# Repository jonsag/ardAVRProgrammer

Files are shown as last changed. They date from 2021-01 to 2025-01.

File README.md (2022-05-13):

# ardATProgrammer

Some code and a shield for programming ATMega328 and ATtiny85

## Additional Boards Managers URL

Insert these URLs in File -> Preferences -> Settings tab  

>damellis: [https://raw.githubusercontent.com/damellis/attiny/ide-1.6.x-boards-manager/package_damellis_attiny_index.json](https://raw.githubusercontent.com/damellis/attiny/ide-1.6.x-boards-manager/package_damellis_attiny_index.json)  
>leonardomilliani: [http://www.leonardomiliani.com/repository/package_leonardomiliani.com_index.json](http://www.leonardomiliani.com/repository/package_leonardomiliani.com_index.json)  
>carlosefr: [https://raw.githubusercontent.com/carlosefr/atmega/master/package_carlosefr_atmega_index.json](https://raw.githubusercontent.com/carlosefr/atmega/master/package_carlosefr_atmega_index.json)  

Then install boards in Tools -> Board -> Boards manager...  

>attiny  
>ATtiny extra Boards  
>ATmega 168P/328P Boards  
>Barebones ATmega Chips (no bootloader)  

## Burn bootloader, settings

### ATtiny85

Board -> ATtiny Microcontrollers -> ATtiny 25/45/85  
Processor -> ATtiny85  
Clock -> ...  
Programmer -> Arduino as ISP  

### ATtiny2313

Board -> ATtiny MCUs -> ATtiny2313/4313  
Micro -> ATtiny2313 @ ...  
Programmer -> Arduino as ISP

### ATmega328P

Board -> Arduino AVR Boards -> Arduino Duemilanove or or Diecimila  
Processor -> ATmega 328P  
Programmer -> Arduino as AVR  

or  

Board -> Atmega168/328 -> Atmega168/328  
Micro -> ATmega328P @ ... w/Arduino as ISP  

### ATmega328

Board -> ATmega Microcontrollers -> ATmega328/328P  
Processor -> ATmega328  
Clock -> ...  
Programmer -> Arduino as ISP  

## Program AVR, settings

### ATtiny85

Board -> ATtiny Microcontrollers -> ATtiny 25/45/85  
Processor -> ATtiny85  
Clock -> ...  
Programmer -> Arduino as ISP

### ATtiny2313

Board -> ATtiny MCUs -> ATtiny2313/4313  
Micro -> ATtiny2313 @ ...  
Programmer -> Arduino as ISP

### ATmega328P

Board -> Arduino AVR Boards -> Arduino Duemilanove or or Diecimila  
Processor -> ATmega 328P  
Programmer -> Arduino as AVR  

or  

Board -> Atmega168/328 -> Atmega168/328  
Micro -> ATmega328P @ ... w/Arduino as ISP

### ATmega328

Board -> ATmega Microcontrollers -> ATmega328/328P  
Processor -> ATmega328  
Clock -> ...  
Programmer -> Arduino as ISP

## Pin Mapping, Arduino IDE -> AVR

### Arduino code -> ATtiny85 pin number -> Pin name -> Function

0 -> 5 -> PB0 -> (PWM, AIN0)  
1 -> 6 -> PB1 -> (PWM, AIN1)  
2 -> 7 -> PB2 -> (ADC1)  
3 -> 2 -> PB3 -> (ADC3)  
4 -> 3 -> PB4 -> (ADC2)  
5 -> 1 -> PB5 -> (RESET, ADC0)  

### Arduino code -> ATmega328 pin number -> Pin name -> Function

  -> 1 -> PC6 -> (RESET)  
0 -> 2 -> PD0 -> Digital pin 0 (Rx)  
1 -> 3 -> PD1 -> Digital pin 1 (Tx)  
2 -> 4 -> PD2 -> Digital pin 2  
3 -> 5 -> PD3 -> Digital pin 3 (PWM)  
4 -> 6 -> PD4 -> Digital pin 4  
5 -> 11 -> PD5 -> Digital pin 5  
6 -> 12 -> PD6 -> Digital pin 6  
7 -> 13 -> PD7 -> Digital pin 7  
8 -> 14 -> PB0 -> Digital pin 8  
9 -> 15 -> PB1 -> Digital pin 9 (PWM)  
10 -> 16 -> PB2 -> Digital pin 10 (PWM)  
11 -> 17 -> PB3 -> Digital pin 11 (PWM)  
12 -> 18 -> PB4 -> Digital pin 12  
13 -> 19 -> PB5 -> Digital pin 13  
14 -> 23 -> PC0 -> Analog input 0  
15 -> 24 -> PC1 -> Analog input 1  
16 -> 25 -> PC2 -> Analog input 2  
17 -> 26 -> PC3 -> Analog input 3  
18 -> 27 -> PC4 -> Analog input 4  
19 -> 28 -> PC5 -> Analog input 5  

## Atmega_Board_Programmer

### attiny85@16MHz internal

#### Before bootburning

>Signature = 0x1E 0x93 0x0B  
>Processor = ATtiny85  
>Flash memory size = 8192 bytes.  
>LFuse = 0x62  
>HFuse = 0xDF  
>EFuse = 0xFF  
>Lock byte = 0xFF  
>Clock calibration = 0x91  
>No bootloader support.  
>  
>First 256 bytes of program memory:  
>  
>00: 0xFF 0xFF 0xFF 0xFF 0xFF 0xFF 0xFF 0xFF ...  

#### After bootburning

>Signature = 0x1E 0x93 0x0B  
>Processor = ATtiny85  
>Flash memory size = 8192 bytes.  
>LFuse = 0xF1  
>HFuse = 0xDF  
>EFuse = 0xFF  
>Lock byte = 0xFF  
>Clock calibration = 0x86  
>No bootloader support.  
>  
>First 256 bytes of program memory:  
>  
>00: 0xFF 0xFF 0xFF 0xFF 0xFF 0xFF 0xFF 0xFF ...  

#### After programming

>Signature = 0x1E 0x93 0x0B  
>Processor = ATtiny85  
>Flash memory size = 8192 bytes.  
>LFuse = 0xF1  
>HFuse = 0xDF  
>EFuse = 0xFF  
>Lock byte = 0xFF  
>Clock calibration = 0x86  
>No bootloader support.  
>  
>First 256 bytes of program memory:  
>  
>00: 0x23 0xC0 0x32 0xC0 0x31 0xC0 0x30 0xC0 ...  

### ATmega328P as 'Arduino Duemilanove or Diecimila'

#### After bootburning

>Signature = 0x1E 0x95 0x0F  
>Processor = ATmega328P  
>Flash memory size = 32768 bytes.  
>LFuse = 0xFF  
>HFuse = 0xDA  
>EFuse = 0xFD  
>Lock byte = 0xCF  
>Clock calibration = 0xA5  
>Bootloader in use: Yes  
>EEPROM preserved through erase: No  
>Watchdog timer always on: No  
>Bootloader is 2048 bytes starting at 7800  
>  
>Bootloader:  
>  
>7800: 0x0C 0x94 0x34 0x3C 0x0C 0x94 0x51 0x3C ...  
>...  
>MD5 sum of bootloader = 0x0A 0xAC 0xF7 0x16 0xF4 0x3C 0xA2 0xC9 0x27 0x7E 0x08 0xB9 0xD6 0x90 0xBC 0x02  
>Bootloader name: ATmegaBOOT_168_atmega328  
>  
>First 256 bytes of program memory:  
>  
>00: 0xFF 0xFF 0xFF 0xFF 0xFF 0xFF 0xFF 0xFF ...  

### ATmega328 as 'ATmega328/328P' @1Mhz Internal

#### After bootburning

>Signature = 0x1E 0x95 0x14  
>Processor = ATmega328  
>Flash memory size = 32768 bytes.  
>LFuse = 0x62  
>HFuse = 0xDB  
>EFuse = 0xFD  
>Lock byte = 0xFF  
>Clock calibration = 0xA9  
>Bootloader in use: No  
>EEPROM preserved through erase: No  
>Watchdog timer always on: No  
>Bootloader is 1024 bytes starting at 7C00  
>  
>Bootloader:  
>  
>7C00: 0xFF 0xFF 0xFF 0xFF 0xFF 0xFF 0xFF 0xFF ...  
>...  
>MD5 sum of bootloader = 0x69 0x42 0x94 0x9C 0x5B 0x44 0x30 0xAE 0xF6 0x63 0x8B 0x89 0xBF 0xE1 0x73 0x2B  
>Bootloader MD5 sum not known.  
>  
>First 256 bytes of program memory:  
>  
>00: 0xFF 0xFF 0xFF 0xFF 0xFF 0xFF 0xFF 0xFF ...  

#### After programming

>Signature = 0x1E 0x95 0x14  
>Processor = ATmega328  
>Flash memory size = 32768 bytes.  
>LFuse = 0x62  
>HFuse = 0x01  
>EFuse = 0xFD  
>Lock byte = 0xFF  
>Clock calibration = 0xA9  
>Bootloader in use: No  
>EEPROM preserved through erase: No  
>Watchdog timer always on: No  
>Bootloader is 2048 bytes starting at 7800  
>  
>Bootloader:  
>  
>7800: 0xFF 0xFF 0xFF 0xFF 0xFF 0xFF 0xFF ...  
>  
>MD5 sum of bootloader = 0xCB 0xAC 0x33 0x2A 0x4E 0x08 0xAC 0xA7 0xCF 0xFF 0xE0 0xB1 0x42 0xAA 0x0C 0x65  
>Bootloader MD5 sum not known.  
>  
>First 256 bytes of program memory:  
>  
>00: 0x0C 0x94 0x5C 0x00 0x0C 0xCD 0x6E 0x00 ...  
### ATmega328 as 'ATmega328/328P' @8Mhz Internal

#### After bootburning  

>Signature = 0x1E 0x95 0x14  
>Processor = ATmega328  
>Flash memory size = 32768 bytes.  
>LFuse = 0xE2  
>HFuse = 0xDB  
>EFuse = 0xFD  
>Lock byte = 0xFF  
>Clock calibration = 0xA8  
>Bootloader in use: No  
>EEPROM preserved through erase: No  
>Watchdog timer always on: No  
>Bootloader is 2048 bytes starting at 7800  
>  
>Bootloader:  
>  
>7800: 0xFF 0xFF 0xFF 0xFF 0xFF 0xFF 0xFF 0xFF ...  
>...  
>MD5 sum of bootloader = 0xE0 0xDE 0xEB 0xD3 0xC3 0xF5 0x60 0x21 0x2A 0xF1 0x7C 0x68 0xB9 0x34 0x4B 0xAE  
>No bootloader (all 0xFF)  
>  
>First 256 bytes of program memory:  
>  
>00: 0xFF 0xFF 0xFF 0xFF 0xFF 0xFF 0xFF 0xFF ...  

#### After programming

>Signature = 0x1E 0x95 0x14  
>Processor = ATmega328  
>Flash memory size = 32768 bytes.  
>LFuse = 0xE2  
>HFuse = 0xDB  
>EFuse = 0xFD  
>Lock byte = 0xFF  
>Clock calibration = 0xA8  
>Bootloader in use: No  
>EEPROM preserved through erase: No  
>Watchdog timer always on: No  
>Bootloader is 2048 bytes starting at 7800  
>  
>Bootloader:  
>  
>7800: 0xFF 0xFF 0xFF 0xFF 0xFF 0xFF 0xFF ...  
>...  
>MD5 sum of bootloader = 0xE0 0xDE 0xEB 0xD3 0xC3 0xF5 0x60 0x21 0x2A 0xF1 0x7C 0x68 0xB9 0x34 0x4B 0xAE  
>No bootloader (all 0xFF)  
>  
>First 256 bytes of program memory:  
>  
>00: 0x0C 0x94 0x5C 0x00 0x0C 0x94 0x6E 0x00 ...  

## Resources

[Breadboard @gammon.com](http://www.gammon.com.au/breadboard) (excellent!)  
[nickgammon arduino sketches @github](https://github.com/nickgammon/arduino_sketches)  
[Alternative Atmega bootloader programmer @gammon.com](http://www.gammon.com.au/forum/?id=11635)  
[Phenoptix @github](https://github.com/phenoptix/AVRISP)

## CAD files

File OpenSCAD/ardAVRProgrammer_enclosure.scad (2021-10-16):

// ardAVRProgrammer_enclosure.scad

// Design: Jon Sagebrand
// jonsagebrand@gmail.com

// pin headers by Niccolo Rigacci <niccolo@rigacci.org>

// arduino module by ?
include <../../myCAD/OpenSCADlibraries/Arduino.scad>

// LED module by ?
include <../../myCAD/OpenSCADlibraries/led.scad>

// NOP scad library by nophead, https://github.com/nophead/NopSCADlib
include <../../myCAD/OpenSCADlibraries/NopSCADlib/vitamins/dip.scad>

// lay out for printing
print = false;

showBottom = true;
showLid = true;

// show arduino board and shield
showArd = true;
showShield = true;

// shield type
// 0: no shield
// 1: ardAVRProgrammer
shieldType = 0;

// make the hole for the arduino power input
powHole = false;

// arduino stand offs
soBotHeight = 4;
soBotDia = 8;

soTopHeight = 1;
soTopDia = 5;

ardMountHoleDia = 2.5;

ardPosts = [[14, 2.5, soBotHeight / 2], 
            [66.1, 7.6, soBotHeight / 2], 
            [66.1, 35.5, soBotHeight / 2], 
            [15.3, 50.7, soBotHeight / 2]];

// arduino uno dimensions
ardWidth = 68.6;
ardDepth = 53.3;
ardHeight = 10.9 + 1.6;

// casing
casWallThick = 1.5;

extraWidthL = shieldType == 0 ? 2 : (shieldType == 1 ? 1 : 5 );
extraWidthR = shieldType == 0 ? 2 : (shieldType == 1 ? 18.5 : 5 );
extraDepthD = shieldType == 0 ? 6 : (shieldType == 1 ? 6.5 : 5 );
extraDepthU = shieldType == 0 ? 6 : (shieldType == 1 ? 12 : 5 );

extraHeight = shieldType == 0 ? 2 : (shieldType == 1 ? 5 : 5 );

// casing lid
lidInset = 2;
lidOffset = 0;

lidScrewHoleDia = 2.5;
lidScrewPostDia = 7;
lidScrewHoleDepth = 7;

lidThick = 1.5;

lidHoleDia = 3.5;

lidRidgeWidth = 2;

tolerance = 0.2;

///// no editing below this line
roundness = 100;

// calculations of casing outer boundaries                                     
casXL = -casWallThick - extraWidthL;
casXR = ardWidth + extraWidthL + extraWidthR + casWallThick * 2 + casXL;
casYD = -casWallThick - extraDepthD;
casYU = ardDepth + extraDepthD + extraDepthU + casWallThick * 2 + casYD;

// lid screw posts                                                             
postsY = soBotHeight + soTopHeight + ardHeight + extraHeight - lidScrewHoleDepth / 2 - lidInset;

lidPostsPos = [[casXL + lidScrewPostDia / 2 + lidOffset, 
                casYD + lidScrewPostDia / 2 + lidOffset, 
                postsY],
	       [casXR - lidScrewPostDia / 2 - lidOffset, 
                casYD + lidScrewPostDia / 2 + lidOffset, 
                postsY],
	       [casXR - lidScrewPostDia / 2 - lidOffset, 
                casYU - lidScrewPostDia / 2 - lidOffset, 
                postsY],
	       [casXL + lidScrewPostDia / 2 + lidOffset, 
                casYU - lidScrewPostDia / 2 - lidOffset, 
                postsY]];

dropPos = [[casXL + casWallThick, 
            casYD + casWallThick, 
            postsY - lidScrewHoleDepth * 1.5],
	   [casXR - casWallThick, 
            casYD + casWallThick, 
            postsY - lidScrewHoleDepth * 1.5],
	   [casXR - casWallThick, 
            casYU - casWallThick, 
            postsY - lidScrewHoleDepth * 1.5],
	   [casXL + casWallThick, 
            casYU - casWallThick, 
            postsY - lidScrewHoleDepth * 1.5]];

////////// the drawing //////////

if ((showArd) && (!print)) {
  translate([0, 53.3, soBotHeight + soTopHeight])
    rotate([0, 0, -90])
    arduinoUno();
 }

if ((showShield) && (!print) && (shieldType)) {
  if (shieldType == 1) {
    translate([0.45, 0.35, 17.9])
      shieldType1();
  }
}

union() {
  if (showBottom) {
    ardMountPosts();
    bottomCasing();
  }
}

//ardMountPosts();
if (showLid) {
  if (print) {
    rotate([180, 0, 0])
      translate([0, 30, 0])
      difference() {
        lid();
        if (shieldType == 1) {
          lidOpeningsType1();
        }
      }
  } else {
    translate([0, 0, soBotHeight + soTopHeight + ardHeight + extraHeight])
    difference() {
      lid();
      if (shieldType == 1) {
        lidOpeningsType1();
      }
    }
  }
 }

module ardMountPosts() {
  for (i = [0 : 1 : 3]) { 
    
    translate(ardPosts[i])
      difference() {
      union() {
	color("blue")
	  cylinder(h = soBotHeight, r1 = soBotDia / 2, r2 = soTopDia / 2, 
		   center = true, $fn = roundness);
	
	color("green")
	  translate([0, 0, soBotHeight / 2 + soTopHeight / 2])
	  cylinder(h = soTopHeight, r1 = soTopDia / 2, r2 = soTopDia / 2, 
		   center = true, $fn = roundness);
	
      }
      
      color("red")
	translate([0, 0, soBotHeight / 2])
        cylinder(h = soBotHeight + soTopHeight, 
		 r1 = ardMountHoleDia / 2, r2 = ardMountHoleDia / 2, 
		 center = true, $fn = roundness);
      
    }
  }
}

module bottomCasing() {
  
  union() {
    translate([-extraWidthL - casWallThick, -extraDepthD - casWallThick, -casWallThick])
      difference() { // bottom part
      color("lightgrey")
	cube([ardWidth + extraWidthL + extraWidthR + casWallThick * 2, 
	      ardDepth + extraDepthD + extraDepthU + casWallThick * 2, 
	      soBotHeight + soTopHeight + ardHeight + casWallThick + extraHeight]);
      
      translate([casWallThick, casWallThick, casWallThick + 0.01])
	color("red")
	cube([ardWidth + extraWidthL + extraWidthR, 
	      ardDepth + extraDepthD + extraDepthU, 
	      soBotHeight + soTopHeight + ardHeight + extraHeight]);
      
      // usb port
      translate([0, 30.2 + casWallThick + extraDepthD, 
		 casWallThick + soBotHeight + soTopHeight])
	color("red")
	cube([casWallThick, 12 + 2, 10.9 + 2]);
      
      // power supply
      if (powHole) {
	translate([0, 3.3 + casWallThick + extraDepthD, 
		   casWallThick + soBotHeight + soTopHeight + 2])
	  union() {
	  //color("red")
	  //cube([casWallThick, 8.9 + 2, 8.9 / 2 + 1]);
	  
	  translate([0, 8.9 / 2 + 1, 8.9 / 2 + 1])
	    rotate([0, 90, 0])
	    cylinder(h = casWallThick, r1 = 8.9 / 2 + 1, r2 = 8.9 / 2 + 1, $fn = roundness);
	}
      }
    }
    
    // lid screw posts
    translate([0, 0, 0])
      for (j = [0 : 1 : 3]) {
	difference() {
	  hull() {
	    translate(lidPostsPos[j])
	      cylinder(h = lidScrewHoleDepth, 
		       r1 = lidScrewPostDia / 2, r2 = lidScrewPostDia / 2, 
		       center = true, $fn = roundness);
	    
	    translate(dropPos[j])
	      cylinder(h = 0.1, r1 = 0.1, r2 = 0.1, center = true, $fn = roundness);
	    
	  }
	  
	  // screw Holes
	  translate(lidPostsPos[j])
	    color("red")
	    cylinder(h = lidScrewHoleDepth, 
		     r1 = lidScrewHoleDia / 2, r2 = lidScrewHoleDia / 2, 
		     center = true, $fn = roundness);
	}
      }    
  }
}

//------------------------------------------------------------------------
// OpenSCAD models of miscellaneous components and devices:
// Pin headers, SD-Card, Edimax WiFi nano dongle, etc.
//
// Author:      Niccolo Rigacci <niccolo@rigacci.org>
// Version:     1.0 2017-12-14
// License:     GNU General Public License v3.0
//------------------------------------------------------------------------

//------------------------------------------------------------------------
// Matrix of 2.54 mm pins.
//------------------------------------------------------------------------
module pin_headers(cols, rows) {
  w = 2.54; h = 2.54; p = 0.65;
  for(x = [0 : (cols -1)]) {
    for(y = [0 : (rows  - 1)]) {
      translate([w * x, w * y, 0]) {
	union() {
	  color("black") 
	    cube([w, w, h]);
	  color("gold")  
	    translate([(w - p) / 2, (w - p) / 2, -3]) cube([p, p, 11.54]);
	}
      }
    }
  }
}

module shieldType1() {
  translate([0, 0, 0]) // PCB
    color("green")
    cube([86.36, 58.42, 1.6]);
  
  // pin headers connecting to Arduino
  translate([28.57 - 2.54, 3.17 - 2.54, 0])
    rotate([180, 0, 90])
    pin_headers(1, 8);
  
  translate([51.44 - 2.54, 3.17 - 2.54, 0])
    rotate([180, 0, 90])
    pin_headers(1, 6);
  
  translate([19.68 - 2.54, 51.44 - 2.54, 0])
    rotate([180, 0, 90])
    pin_headers(1, 10);
  
  translate([46.35 - 2.54, 51.44 - 2.54, 0])
    rotate([180, 0, 90])
    pin_headers(1, 8);
  
  // LEDs
  //translate([79.38, 54.61, 1.6 + 1.5])
  translate([80.64, 54.61, 1.6 + 1.5])
    led(5, "blue", legs = false);

  translate([80.64, 46.35, 1.6 + 1.5])
    led(5, "red", legs = false);
  
  translate([80.64, 38.10, 1.6 + 1.5])
    led(5, "green", legs = false);
  
  // headers
  translate([59.69 - 2.54 / 2, 13.34 - 2.54 / 2, 2.54 / 2 + 0.4])
    rotate([0, 0, 0])
    pin_headers(2, 3);
  
  translate([59.69 - 2.54 / 2, 28.57 - 2.54 / 2, 2.54 / 2 + 0.4])
    rotate([0, 0, 0])
    pin_headers(2, 5);
  
  
  //  28 pin ZIF
  translate([11.43, 12.06, 1.7])
    zif28();
  /*
    translate([11.43 + 2.54 * 6.5, 12.7 + 2.54 * 2, 1.7])
    rotate([0, 0, 90])
    pdip(28, 2.54, socketed = true, w = inch(0.4));
  */
  // 20 pin ZIF
  translate([21.59, 35.56, 1.7])
    zif20();
  /*
    translate([21.59 + 2.54 * 4.5, 36.2 + 2.54 * 1.5, 1.7])
    rotate([0, 0, 90])
    pdip(20, 2.54, socketed = true, w = inch(0.3));
  */
  // 8 pin DIL
  translate([74.3 + 2.54 * 1.5, 5.08 + 2.54 * 1.5, 1.7])
    rotate([0, 0, 0])
    pdip(8, 2.54, socketed = true, w = inch(0.3));
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

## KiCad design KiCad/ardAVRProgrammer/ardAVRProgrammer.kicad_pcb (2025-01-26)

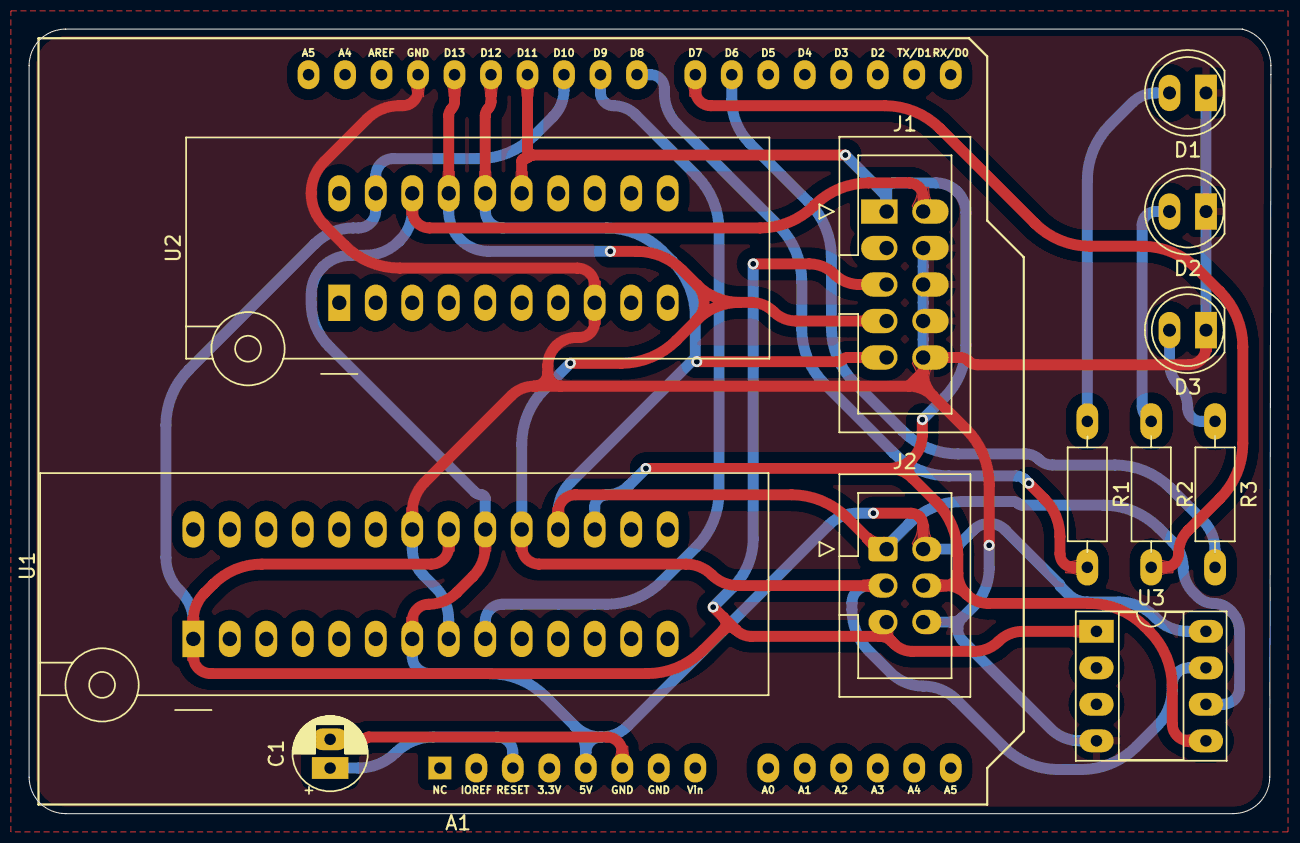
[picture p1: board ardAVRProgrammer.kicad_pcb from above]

Board: 2 copper layers, 86.4 x 54.6 mm, 13 parts (0 on the bottom side), 15 nets.

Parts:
A1: Arduino_UNO_R3; Arduino_UNO_R3_shield_large
C1: 10u; CP_Radial_D5.0mm_P2.00mm_larger
D1, D2, D3: LED; LED_D5.0mm_larger_pads
J1: 2x5_ISP_header; IDC-Header_2x05_P2.54mm_Vertical_large
J2: 2x3_ISP_header; IDC-Header_2x03_P2.54mm_Vertical large
R1, R2, R3: 330R; R_Axial_DIN0207_L6.3mm_D2.5mm_P10.16mm_Horizontal_larger_pa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
U1: ATmega328P-PU; ZIF_DIP_Socket-28_W6.9_W7.62_W7.62_W12.7_W13.5_large
U2: ATtiny2313-20M; ZIF_DIP_Socket-20_W4.3_W5.08_W7.62_W10.16_W10.9_3M_220-3342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
U3: ATtiny85-20P; DIP-8_W7.62mm_Socket_w_dip_packet_LongPads

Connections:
+5V: A1.5 (+5V), J1.2 (VCC), J2.2 (VCC), U1.7 (VCC), U1.20 (AVCC), U2.18 (VCC), U3.8 (VCC)
GND: A1.29 (GND), D1.1 (K), D2.1 (K), D3.1 (K), J1.4 (GND), J1.6 (GND), J1.8 (GND), J1.10 (GND), J2.6 (GND), U1.8 (GND), U1.22 (GND), U2.8 (GND), U3.4 (GND)
unnamed: A1.3 (~RESET), C1.1
unnamed: A1.6 (GND), C1.2
unnamed: A1.21 (D6), R3.2
unnamed: A1.22 (D7), R2.2
unnamed: A1.23 (D8), R1.2
unnamed: A1.24 (D9), U1.9 (XTAL1/PB6)
unnamed: A1.25 (D10), J1.5 (RST), J2.5 (RST), U1.1 (~RESET/PC6), U1.21 (AREF), U2.19 (PA2/~RESET), U3.1 (~RESET/PB5)
unnamed: A1.26 (D11), J1.1 (MOSI), J2.4 (MOSI), U1.17 (PB3), U2.15 (PB5), U3.5 (AREF/PB0)
unnamed: A1.27 (D12), J1.9 (MISO), J2.1 (MISO), U1.18 (PB4), U2.16 (PB6), U3.6 (PB1)
unnamed: A1.28 (D13), J1.7 (SCK), J2.3 (SCK), U1.19 (PB5), U2.17 (PB7), U3.7 (PB2)
unnamed: D1.2 (A), R1.1
unnamed: D2.2 (A), R2.1
unnamed: D3.2 (A), R3.1

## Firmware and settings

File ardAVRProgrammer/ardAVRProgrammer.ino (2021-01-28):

/* ardAVRProgrammer
 *  
 * by phenoptix
 * code from https://www.instructables.com/Building-an-ISP-Shield-for-Arduino/ 
 * 
 * /

/* Making a barebones arduino
 *  
 *  instructions from https://www.instructables.com/Programming-Chips-With-Your-Arduino-AVR-ISP-Coveri/
 *  
 *  Go to > Tools on your IDE, 
 *  Now > Programmer > Arduino as ISP. 
 *  With that checked we can then go back to > Tools > Burn Bootloader. 
 *  Now we're going to see some flashing LEDs and wait a while. 
 *  The message at the bottom of your IDE should eventually turn to Bootloading complete. 
 *  Hey presto, that chip on the breadboard can now be turned into a barebones Arduino!
 *  such as on http://start.shrimping.it/kit/shrimp.html
 *  
 */

 
// this sketch turns the Arduino into a AVRISP
// using the following pins:
// 10: slave reset
// 11: MOSI
// 12: MISO
// 13: SCK

// Put an LED (with resistor) on the following pins:
//  7: Error - Lights up if something goes wrong (use red if that makes sense)
//  8: Programming - In communication with the slave
//  6: Heartbeat - shows the programmer is running (removed, see notes below)
// Optional - Piezo speaker on pin A3
//
// October 2009 by David A. Mellis
// - Added support for the read signature command
//
// February 2009 by Randall Bohn
// - Added support for writing to EEPROM (what took so long?)
// Windows users should consider WinAVR's avrdude instead of the
// avrdude included with Arduino software.
//
// January 2008 by Randall Bohn
// - Thanks to Amplificar for helping me with the STK500 protocol
// - The AVRISP/STK500 (mk I) protocol is used in the arduino bootloader
// - The SPI functions herein were developed for the AVR910_ARD programmer
// - More information at http://code.google.com/p/mega-isp
//
// March 2012 - William Phelps
// modify to work with Arduino IDE 1.0 which has a shorter serial port receive buffer
// getEOP() now gets entire request before avrisp() is called to process it
// Serial.print((char) xxx) changed to Serial.write(xxx)
// uint8_t changed to byte
// added support for Piezo speaker
// moved Pmode LED to A0
// removed "heartbeat" on pin 6, added short blip of ERROR LED instead
// Why is it that PROG_FLASH and PROG_DATA don't actually do anything???
// Tested with Arduino IDE 22 and 1.0
// IDE 22 - 5148 bytes
// IDE 1.0 - 5524 bytes!

// January 2014 - Ben Gray
// Put the heartbeat LED back and switched around the pins a little for the LEDs.


// SLOW SPEED CHIP ERASE AND FUSE BURNING
//
// Enable LOW_SPEED to allow you to erase chips that would fail otherwise,
// for being running with a clock too slow for the programmer.
//
// This allowed me to recover several ATMega328 that had no boot loader and the
// first instruction was to set the clock to the slowest speed. Usually this
// kind of recovery requires high voltage programming, but this trick will do
// just fine.
//
// How to proceed:
// 1. Enable LOW_SPEED, and load it to the programmer.
// 2. Erase and burn the fuses on the target uC. Example for ATMega328:
//   arduino-1.0.1/hardware/tools/avrdude -Carduino-1.0.1/hardware/tools/avrdude.conf -patmega328p -cstk500v1 -P /dev/serial/by-id/usb-FTDI_FT232R_USB_UART_A900cf1Q-if00-port0 -b19200 -e -Ulock:w:0x3F:m -Uefuse:w:0x05:m -Uhfuse:w:0xDA:m -Ulfuse:w:0xF7:m
// 3. Comment LOW_SPEED and load it back to the programmer.
// 4. Program the target uC as usual. Example:
//  arduino-1.0.1/hardware/tools/avrdude -Carduino-1.0.1/hardware/tools/avrdude.conf -patmega328p -cstk500v1 -P /dev/serial/by-id/usb-FTDI_FT232R_USB_UART_A900cf1Q-if00-port0 -b19200 -Uflash:w:firmware.hex:i
//
// Note 1: EXTRA_SPI_DELAY was added to let you slow down SPI even more. You can
// play with the value if it does not work with the default.
// Note 2: LOW_SPEED will alow you only to erase the chip and burn the fuses! It
// will fail if you try to program the target uC this way!

//#define LOW_SPEED
#ifdef LOW_SPEED
#define EXTRA_SPI_DELAY 125
#else
#define EXTRA_SPI_DELAY 0
#endif

#include "pins_arduino.h"  // defines SS,MOSI,MISO,SCK
#define RESET SS

#define LED_ERR 7
#define LED_PMODE 8
#define LED_HB 6
//#define PIEZO A3

#define HWVER 2
#define SWMAJ 1
#define SWMIN 18

// STK Definitions
const byte STK_OK = 0x10;
const byte STK_FAILED = 0x11;
const byte STK_UNKNOWN = 0x12;
const byte STK_INSYNC = 0x14;
const byte STK_NOSYNC = 0x15;
const byte CRC_EOP = 0x20; //ok it is a space...

const byte STK_GET_SYNC     = 0x30;
const byte STK_GET_SIGNON   = 0x31;
const byte STK_GET_PARM     = 0x41;
const byte STK_SET_PARM     = 0x42;
const byte STK_SET_PARM_EXT = 0x45;
const byte STK_PMODE_START  = 0x50;
const byte STK_PMODE_END    = 0x51;
const byte STK_SET_ADDR     = 0x55;
const byte STK_UNIVERSAL    = 0x56;
const byte STK_PROG_FLASH   = 0x60;
const byte STK_PROG_DATA    = 0x61;
const byte STK_PROG_PAGE    = 0x64;
const byte STK_READ_PAGE    = 0x74;
const byte STK_READ_SIGN    = 0x75;

//// TONES  ==========================================
//// Start by defining the relationship between
////       note, period, &  frequency.
//#define  c     3830    // 261 Hz
//#define  d     3400    // 294 Hz
//#define  e     3038    // 329 Hz
//#define  f     2864    // 349 Hz
//#define  g     2550    // 392 Hz
//#define  a     2272    // 440 Hz
//#define  b     2028    // 493 Hz
//#define  C     1912    // 523 Hz

//void pulse(int pin, int times);

int error = 0;
int pmode = 0;
// address for reading and writing, set by STK_SET_ADDR command
int _addr;
byte _buffer[256]; // serial port buffer
int pBuffer = 0;  // buffer pointer
int iBuffer = 0;  // buffer index
byte buff[256];  // temporary buffer
boolean EOP_SEEN = false;

void setup() {

  Serial.begin(19200);
  //  pinMode(PIEZO, OUTPUT);
  //  beep(1700, 40);
  EOP_SEEN = false;
  iBuffer = pBuffer = 0;

  pinMode(LED_PMODE, OUTPUT);
  pulse(LED_PMODE, 2);
  pinMode(LED_ERR, OUTPUT);
  pulse(LED_ERR, 2);
  pinMode(LED_HB, OUTPUT);
  pulse(LED_HB, 2);

  pinMode(9, OUTPUT);
  // setup high freq PWM on pin 9 (timer 1)
  // 50% duty cycle -> 8 MHz
  OCR1A = 0;
  ICR1 = 1;
  // OC1A output, fast PWM
  TCCR1A = _BV(WGM11) | _BV(COM1A1);
  TCCR1B = _BV(WGM13) | _BV(WGM12) | _BV(CS10); // no clock prescale


}

#define beget16(addr) (*addr * 256 + *(addr+1) )
typedef struct param {
  byte devicecode;
  byte revision;
  byte progtype;
  byte parmode;
  byte polling;
  byte selftimed;
  byte lockbytes;
  byte fusebytes;
  int flashpoll;
  int eeprompoll;
  int pagesize;
  int eepromsize;
  int flashsize;
}
parameter;

parameter param;

// this provides a heartbeat on pin 6, so you can tell the software is running.
byte hbval = 128;
int8_t hbdelta = 4;
void heartbeat() {
  if (hbval > 192) hbdelta = -hbdelta;
  if (hbval < 32) hbdelta = -hbdelta;
  if (hbval > 250) hbdelta = -hbdelta;
  if (hbval < 10) hbdelta = -hbdelta;
  hbval += hbdelta;
  analogWrite(LED_HB, hbval);
  delay(20);
}

void getEOP() {
  int minL = 0;
  byte avrch = 0;
  byte bl = 0;
  while (!EOP_SEEN) {
    while (Serial.available() > 0) {
      byte ch = Serial.read();
      _buffer[iBuffer] = ch;
      iBuffer = (++iBuffer) % 256; // increment and wrap
      if (iBuffer == 1)  avrch = ch;  // save command
      if ((avrch == STK_PROG_PAGE) && (iBuffer == 3)) {
        minL = 256 * _buffer[1] + _buffer[2] + 4;
      }
      if ((iBuffer > minL) && (ch == CRC_EOP)) {
        EOP_SEEN = true;
      }
    }
    if (!EOP_SEEN) {
      heartbeat(); // light the heartbeat LED
      //     if (bl == 100) {
      //       pulse(LED_ERR,1,10);  // blink the red LED
      //       bl = 0;
      //     }
      bl++;
      delay(10);
    }
  }
}

// serialEvent not used so sketch would be compatible with older IDE versions
//void serialEvent() {
//  int minL = 0;
//  byte avrch = 0;
//  while (Serial.available()>0)
//  {
//    byte ch = Serial.read();
//    _buffer[iBuffer] = ch;
//    iBuffer = (++iBuffer)%256;  // increment and wrap
//    if (iBuffer == 1)  avrch = ch;  // save command
//    if ((avrch == STK_PROG_PAGE) && (iBuffer==3)) {
//      minL = 256*_buffer[1] + _buffer[2] + 4;
//    }
//    if ((iBuffer>minL) && (ch == CRC_EOP)) {
//      EOP_SEEN = true;
//    }
//  }
//}

void loop(void) {
  // is pmode active?
  //  if (pmode) digitalWrite(LED_PMODE, HIGH);
  //  else digitalWrite(LED_PMODE, LOW);
  digitalWrite(LED_PMODE, LOW);
  // is there an error?
  if (error) digitalWrite(LED_ERR, HIGH);
  else digitalWrite(LED_ERR, LOW);

  getEOP();

  // have we received a complete request?  (ends with CRC_EOP)
  if (EOP_SEEN) {
    digitalWrite(LED_PMODE, HIGH);
    EOP_SEEN = false;
    avrisp();
    iBuffer = pBuffer = 0;  // restart buffer
  }

}

byte getch() {
  if (pBuffer == iBuffer) {  // spin until data available ???
    pulse(LED_ERR, 1);
    //    beep(1700, 20);
    error++;
    return -1;
  }
  byte ch = _buffer[pBuffer];  // get next char
  pBuffer = (++pBuffer) % 256; // increment and wrap
  return ch;
}

void readbytes(int n) {
  for (int x = 0; x < n; x++) {
    buff[x] = getch();
  }
}

//#define PTIME 20
void pulse(int pin, int times, int ptime) {
  do {
    digitalWrite(pin, HIGH);
    delay(ptime);
    digitalWrite(pin, LOW);
    delay(ptime);
    times--;
  }
  while (times > 0);
}
void pulse(int pin, int times) {
  pulse(pin, times, 50);
}

void spi_init() {
  byte x;
  SPCR = 0x53;
#ifdef LOW_SPEED
  SPCR = SPCR | B00000011;
#endif
  x = SPSR;
  x = SPDR;
}

void spi_wait() {
  do {
  }
  while (!(SPSR & (1 << SPIF)));
}

byte spi_send(byte b) {
  byte reply;
#ifdef LOW_SPEED
  cli();
  CLKPR = B10000000;
  CLKPR = B00000011;
  sei();
#endif
  SPDR = b;
  spi_wait();
  reply = SPDR;
#ifdef LOW_SPEED
  cli();
  CLKPR = B10000000;
  CLKPR = B00000000;
  sei();
#endif
  return reply;
}

byte spi_transaction(byte a, byte b, byte c, byte d) {
  byte n;
  spi_send(a);
  n = spi_send(b);
  //if (n != a) error = -1;
  n = spi_send(c);
  return spi_send(d);
}

void replyOK() {
  //  if (EOP_SEEN == true) {
  if (CRC_EOP == getch()) {  // EOP should be next char
    Serial.write(STK_INSYNC);
    Serial.write(STK_OK);
  }
  else {
    pulse(LED_ERR, 2);
    Serial.write(STK_NOSYNC);
    error++;
  }
}

void breply(byte b) {
  if (CRC_EOP == getch()) {  // EOP should be next char
    Serial.write(STK_INSYNC);
    Serial.write(b);
    Serial.write(STK_OK);
  }
  else {
    Serial.write(STK_NOSYNC);
    error++;
  }
}

void get_parameter(byte c) {
  switch (c) {
    case 0x80:
      breply(HWVER);
      break;
    case 0x81:
      breply(SWMAJ);
      break;
    case 0x82:
      breply(SWMIN);
      break;
    case 0x93:
      breply('S'); // serial programmer
      break;
    default:
      breply(0);
  }
}

void set_parameters() {
  // call this after reading paramter packet into buff[]
  param.devicecode = buff[0];
  param.revision = buff[1];
  param.progtype = buff[2];
  param.parmode = buff[3];
  param.polling = buff[4];
  param.selftimed = buff[5];
  param.lockbytes = buff[6];
  param.fusebytes = buff[7];
  param.flashpoll = buff[8];
  // ignore buff[9] (= buff[8])
  //getch(); // discard second value

  // WARNING: not sure about the byte order of the following
  // following are 16 bits (big endian)
  param.eeprompoll = beget16(&buff[10]);
  param.pagesize = beget16(&buff[12]);
  param.eepromsize = beget16(&buff[14]);

  // 32 bits flashsize (big endian)
  param.flashsize = buff[16] * 0x01000000
                    + buff[17] * 0x00010000
                    + buff[18] * 0x00000100
                    + buff[19];

}

void start_pmode() {
  spi_init();
  // following delays may not work on all targets...
  pinMode(RESET, OUTPUT);
  digitalWrite(RESET, HIGH);
  pinMode(SCK, OUTPUT);
  digitalWrite(SCK, LOW);
  delay(50 + EXTRA_SPI_DELAY);
  digitalWrite(RESET, LOW);
  delay(50 + EXTRA_SPI_DELAY);
  pinMode(MISO, INPUT);
  pinMode(MOSI, OUTPUT);
  spi_transaction(0xAC, 0x53, 0x00, 0x00);
  pmode = 1;
}

void end_pmode() {
  pinMode(MISO, INPUT);
  pinMode(MOSI, INPUT);
  pinMode(SCK, INPUT);
  pinMode(RESET, INPUT);
  pmode = 0;
}

void universal() {
  //  int w;
  byte ch;
  //  for (w = 0; w < 4; w++) {
  //    buff[w] = getch();
  //  }
  readbytes(4);
  ch = spi_transaction(buff[0], buff[1], buff[2], buff[3]);
  breply(ch);
}

void flash(byte hilo, int addr, byte data) {
  spi_transaction(0x40 + 8 * hilo, addr >> 8 & 0xFF, addr & 0xFF, data);
}
void commit(int addr) {
  spi_transaction(0x4C, (addr >> 8) & 0xFF, addr & 0xFF, 0);
}

//#define _current_page(x) (here & 0xFFFFE0)
int current_page(int addr) {
  if (param.pagesize == 32) return addr & 0xFFFFFFF0;
  if (param.pagesize == 64) return addr & 0xFFFFFFE0;
  if (param.pagesize == 128) return addr & 0xFFFFFFC0;
  if (param.pagesize == 256) return addr & 0xFFFFFF80;
  return addr;
}
byte write_flash(int length) {
  if (param.pagesize < 1) {
    return STK_FAILED;
  }
  //if (param.pagesize != 64) return STK_FAILED;
  int page = current_page(_addr);
  int x = 0;
  while (x < length) {
    if (page != current_page(_addr)) {
      commit(page);
      page = current_page(_addr);
    }
    flash(LOW, _addr, buff[x++]);
    flash(HIGH, _addr, buff[x++]);
    _addr++;
  }
  commit(page);
  return STK_OK;
}

byte write_eeprom(int length) {
  // here is a word address, so we use here*2
  // this writes byte-by-byte,
  // page writing may be faster (4 bytes at a time)
  for (int x = 0; x < length; x++) {
    spi_transaction(0xC0, 0x00, _addr * 2 + x, buff[x]);
    delay(45);
  }
  return STK_OK;
}

void program_page() {
  byte result = STK_FAILED;
  int length = 256 * getch() + getch();
  if (length > 256) {
    Serial.write(STK_FAILED);
    error++;
    return;
  }
  char memtype = (char)getch();
  //  for (int x = 0; x < length; x++) {
  //    buff[x] = getch();
  //  }
  readbytes(length);
  if (CRC_EOP == getch()) {
    Serial.write(STK_INSYNC);
    switch (memtype) {
      case 'E':
        result = (byte)write_eeprom(length);
        break;
      case 'F':
        result = (byte)write_flash(length);
        break;
    }
    Serial.write(result);
    if (result != STK_OK) {
      error++;
    }
  }
  else {
    Serial.write(STK_NOSYNC);
    error++;
  }
}

byte flash_read(byte hilo, int addr) {
  return spi_transaction(0x20 + hilo * 8,
                         (addr >> 8) & 0xFF,
                         addr & 0xFF,
                         0);
}

char flash_read_page(int length) {
  for (int x = 0; x < length; x += 2) {
    byte low = flash_read(LOW, _addr);
    Serial.write( low);
    byte high = flash_read(HIGH, _addr);
    Serial.write( high);
    _addr++;
  }
  return STK_OK;
}

char eeprom_read_page(int length) {
  // here again we have a word address
  for (int x = 0; x < length; x++) {
    byte ee = spi_transaction(0xA0, 0x00, _addr * 2 + x, 0xFF);
    Serial.write( ee);
  }
  return STK_OK;
}

void read_page() {
  byte result = (byte)STK_FAILED;
  int length = 256 * getch() + getch();
  char memtype = getch();
  if (CRC_EOP != getch()) {
    Serial.write(STK_NOSYNC);
    return;
  }
  Serial.write(STK_INSYNC);
  if (memtype == 'F') result = flash_read_page(length);
  if (memtype == 'E') result = eeprom_read_page(length);
  Serial.write(result);
  return;
}

void read_signature() {
  if (CRC_EOP != getch()) {
    Serial.write(STK_NOSYNC);
    error++;
    return;
  }
  Serial.write(STK_INSYNC);
  byte high = spi_transaction(0x30, 0x00, 0x00, 0x00);
  Serial.write(high);
  byte middle = spi_transaction(0x30, 0x00, 0x01, 0x00);
  Serial.write(middle);
  byte low = spi_transaction(0x30, 0x00, 0x02, 0x00);
  Serial.write(low);
  Serial.write(STK_OK);
}
//////////////////////////////////////////
//////////////////////////////////////////


////////////////////////////////////
////////////////////////////////////

int avrisp() {
  byte data, low, high;
  byte avrch = getch();
  switch (avrch) {
    case STK_GET_SYNC: // get in sync
      replyOK();
      break;
    case STK_GET_SIGNON:  // get sign on
      if (getch() == CRC_EOP) {
        Serial.write(STK_INSYNC);
        Serial.write("AVR ISP");
        Serial.write(STK_OK);
      }
      break;
    case STK_GET_PARM:  // 0x41
      get_parameter(getch());
      break;
    case STK_SET_PARM:  // 0x42
      readbytes(20);
      set_parameters();
      replyOK();
      break;
    case STK_SET_PARM_EXT: // extended parameters - ignore for now
      readbytes(5);
      replyOK();
      break;
    case STK_PMODE_START:  // 0x50
      //     beep(2272, 20);
      start_pmode();
      replyOK();
      break;
    case STK_PMODE_END:  //0x51
      //      beep(1912, 50);
      error = 0;
      end_pmode();
      replyOK();
      break;
    case STK_SET_ADDR:  // 0x55
      _addr = getch() + 256 * getch();
      replyOK();
      break;
    case STK_UNIVERSAL:  //UNIVERSAL 0x56
      universal();
      break;
    case STK_PROG_FLASH: //STK_PROG_FLASH  ???
      low = getch();
      high = getch();
      replyOK();
      break;
    case STK_PROG_DATA: //STK_PROG_DATA  ???
      data = getch();
      replyOK();
      break;
    case STK_PROG_PAGE:  //STK_PROG_PAGE
      //      beep(1912, 20);
      program_page();
      break;
    case STK_READ_PAGE: //STK_READ_PAGE
      read_page();
      break;
    case STK_READ_SIGN: //STK_READ_SIGN
      read_signature();
      break;
    // expecting a command, not CRC_EOP
    // this is how we can get back in sync
    case CRC_EOP:
      Serial.write(STK_NOSYNC);
      break;
    // anything else we will return STK_UNKNOWN
    default:
      if (CRC_EOP == getch())
        Serial.write(STK_UNKNOWN);
      else
        Serial.write(STK_NOSYNC);
  }
}

// beep without using PWM
//void beep(int tone, long duration){
//  long elapsed = 0;
//  while (elapsed < (duration * 10000)) {
//    digitalWrite(PIEZO, HIGH);
//    delayMicroseconds(tone / 2);
//    digitalWrite(PIEZO, LOW);
//    delayMicroseconds(tone / 2);
// Keep track of how long we pulsed
//    elapsed += tone;
//  }
//}

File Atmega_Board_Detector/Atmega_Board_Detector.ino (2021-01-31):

// Atmega chip fuse detector
// Author: Nick Gammon
// Date: 19nd March 2017
// Version: 1.20

// Version 1.1 added signatures for Attiny24/44/84 (5 May 2012)
// Version 1.2 added signatures for ATmega8U2/16U2/32U2 (7 May 2012)
// Version 1.3: Added signature for ATmega1284P (8 May 2012)
// Version 1.4: Output an 8 MHz clock on pin 9
// Version 1.5: Corrected flash size for Atmega1284P.
// Version 1.6: Added signatures for ATtiny2313A, ATtiny4313, ATtiny13
// Version 1.7: Added signature for Atmega8A
// Version 1.8: Allowed for running on the Leonardo, Micro, etc.
// Version 1.9: Fixed bug where wrong fuse was being checked for bootloader in some cases
// Version 1.10: Added database of known signatures
// Version 1.11: Added MD5 sum for Uno Atmega16U2 (USB) bootloader
// Version 1.12: Display message if cannot enter programming mode.
// Version 1.13: Added support for At90USB82, At90USB162
// Version 1.14: Added support for ATmega328
// Version 1.15: Added preliminary support for high-voltage programming mode for Atmega328 family
// Version 1.16: Major tidy-ups, made code more modular
// Version 1.17: Added signature for Leonardo_prod_firmware_2012_12_10 bootloader
// Version 1.18: Got rid of compiler warnings in IDE 1.6.7
// Version 1.19: Added more signatures: ATmega168V, ATmega328PB, ATmega1284
// Version 1.20: Added MD5 sum for Pro Mini Optiboot bootloader (19 March 2017 by Patrick Bouffel)

const char Version [] = "1.20";

// make true to use the high-voltage parallel wiring
#define HIGH_VOLTAGE_PARALLEL false
// make true to use the high-voltage serial wiring
#define HIGH_VOLTAGE_SERIAL false
// make true to use ICSP programming
#define ICSP_PROGRAMMING true

#if HIGH_VOLTAGE_PARALLEL && HIGH_VOLTAGE_SERIAL
  #error Cannot use both high-voltage parallel and serial at the same time
#endif 

#if (HIGH_VOLTAGE_PARALLEL || HIGH_VOLTAGE_SERIAL) && ICSP_PROGRAMMING
  #error Cannot use ICSP and high-voltage programming at the same time
#endif

#if !(HIGH_VOLTAGE_PARALLEL || HIGH_VOLTAGE_SERIAL || ICSP_PROGRAMMING)
  #error Choose a programming mode: HIGH_VOLTAGE_PARALLEL, HIGH_VOLTAGE_SERIAL or ICSP_PROGRAMMING 
#endif

#define USE_BIT_BANGED_SPI false

/*

 Copyright 2012 Nick Gammon.


 PERMISSION TO DISTRIBUTE

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

 LIMITATION OF LIABILITY

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
*/
#pragma GCC optimize ("-O0") // avoid GCC memcpy inline

#include <SPI.h>
extern "C"
  {
  #include "md5.h"
  }

const byte CLOCKOUT = 9;
const byte RESET = 10;  // --> goes to reset on the target board

const int ENTER_PROGRAMMING_ATTEMPTS = 50;

#if ARDUINO < 100
  const byte SCK = 13;    // SPI clock
#endif

#include "HV_Pins.h"
#include "Signatures.h"
#include "General_Stuff.h"
#include <string.h>  // needed for memcpy

// for looking up known signatures
typedef struct {
   byte md5sum [16];
   char const * filename;
} deviceDatabaseType;

// These are bootloaders we know about.

const char ATmegaBOOT_168_atmega328             [] PROGMEM = "ATmegaBOOT_168_atmega328";
const char ATmegaBOOT_168_atmega328_pro_8MHz    [] PROGMEM = "ATmegaBOOT_168_atmega328_pro_8MHz";
const char ATmegaBOOT_168_atmega1280            [] PROGMEM = "ATmegaBOOT_168_atmega1280";
const char ATmegaBOOT_168_diecimila             [] PROGMEM = "ATmegaBOOT_168_diecimila";
const char ATmegaBOOT_168_ng                    [] PROGMEM = "ATmegaBOOT_168_ng";
const char ATmegaBOOT_168_pro_8MHz              [] PROGMEM = "ATmegaBOOT_168_pro_8MHz";
const char ATmegaBOOT                           [] PROGMEM = "ATmegaBOOT";
const char ATmegaBOOT_168                       [] PROGMEM = "ATmegaBOOT_168";
const char ATmegaBOOT_168_atmega328_bt          [] PROGMEM = "ATmegaBOOT_168_atmega328_bt";
const char LilyPadBOOT_168                      [] PROGMEM = "LilyPadBOOT_168";
const char optiboot_atmega328_IDE_0022          [] PROGMEM = "optiboot_atmega328_IDE_0022";
const char optiboot_atmega328_pro_8MHz          [] PROGMEM = "optiboot_atmega328_pro_8MHz";
const char optiboot_lilypad                     [] PROGMEM = "optiboot_lilypad";
const char optiboot_luminet                     [] PROGMEM = "optiboot_luminet";
const char optiboot_pro_16MHz                   [] PROGMEM = "optiboot_pro_16MHz";
const char optiboot_pro_20mhz                   [] PROGMEM = "optiboot_pro_20mhz";
const char stk500boot_v2_mega2560               [] PROGMEM = "stk500boot_v2_mega2560";
const char DiskLoader_Leonardo                  [] PROGMEM = "DiskLoader-Leonardo";
const char optiboot_atmega8                     [] PROGMEM = "optiboot_atmega8";
const char optiboot_atmega168                   [] PROGMEM = "optiboot_atmega168";
const char optiboot_atmega328                   [] PROGMEM = "optiboot_atmega328";
const char optiboot_atmega328_Mini              [] PROGMEM = "optiboot_atmega328-Mini";
const char ATmegaBOOT_324P                      [] PROGMEM = "ATmegaBOOT_324P";
const char ATmegaBOOT_644                       [] PROGMEM = "ATmegaBOOT_644";
const char ATmegaBOOT_644P                      [] PROGMEM = "ATmegaBOOT_644P";
const char Mega2560_Original                    [] PROGMEM = "Mega2560_Original";
const char optiboot_atmega1284p                 [] PROGMEM = "optiboot_atmega1284p";
const char Ruggeduino                           [] PROGMEM = "Ruggeduino";
const char Leonardo_prod_firmware_2012_04_26    [] PROGMEM = "Leonardo-prod-firmware-2012-04-26";
const char Leonardo_prod_firmware_2012_12_10    [] PROGMEM = "Leonardo-prod-firmware-2012-12-10";
const char atmega2560_bootloader_wd_bug_fixed   [] PROGMEM = "atmega2560_bootloader_watchdog_bug_fixed";
const char Caterina_Esplora                     [] PROGMEM = "Esplora";
const char Sanguino_ATmegaBOOT_644P             [] PROGMEM = "Sanguino_ATmegaBOOT_644P";
const char Sanguino_ATmegaBOOT_168_atmega644p   [] PROGMEM = "Sanguino_ATmegaBOOT_168_atmega644p";
const char Sanguino_ATmegaBOOT_168_atmega1284p  [] PROGMEM = "Sanguino_ATmegaBOOT_168_atmega1284p";
const char Sanguino_ATmegaBOOT_168_atmega1284p_8m [] PROGMEM = "Sanguino_ATmegaBOOT_168_atmega1284p_8m";
const char Arduino_dfu_usbserial_atmega16u2_Uno_Rev3 [] PROGMEM = "Arduino-dfu-usbserial-atmega16u2-Uno-Rev3";
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

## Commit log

2021-01-29 deleted unnecessary files
    [ardAVRProgrammer_enclosure-0.1-bottom.3mf, ardAVRProgrammer_enclosure-0.1-bottom.stl, ardAVRProgrammer_enclosure-0.1-lid.3mf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]
2021-01-29 new schematics
    [ardATProgrammer.sch, ardAVRProgrammer2.kicad_pcb, ardAVRProgrammer2.sch]
2021-01-29 schematics and scad
    [ardATProgrammer.sch, ardAVRProgrammer_enclosure.scad]
2021-01-30 ATmega Board Detector
2021-01-31 Board detector
2022-05-17 new PCB layout
    [ardAVRProgrammer.kicad_pcb, ardAVRProgrammer.kicad_sch]
2022-06-03 new kicad
    [ardATProgrammer.kicad_pcb, ardATProgrammer.kicad_sch, ardAVRProgrammer.kicad_pcb]
2025-01-26 new kicad version
    [ardAVRProgrammer.kicad_pcb, ardAVRProgrammer.kicad_sch]
